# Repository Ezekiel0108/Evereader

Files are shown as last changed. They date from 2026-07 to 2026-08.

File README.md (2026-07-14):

# Evereader
## What is it?
It is an esp32-s3 module based e-reader with dual screens that should be easy enough for anyone to build and customize.
### Why does this project exist?
There are two main reasons:
1. I really wanted to make a project bigger than what i had done until now, i want to give back at least in some way to the foss community;
2. I have been getting a lot into reading lately and i really wanted an e-reader, but none of them actually felt right for me, either they where too big to put in a pocket or the smaller ones just didn't fit enough content for my taste.
### Why two screens?
1. Why not?
2. I really wanted to keep the form factor pocketable without sacrificing text on screen, so i put two!
#### State of developement
I am currently just ending the breadboard circuit, after that i want to start making the PCB and develop the firmware.
#### TO-DO list
- [x] Finish up the breadboard circuit.
- [ ] Finish up the PCB kicad project.
- [ ] Finish up the software.
- [ ] Refine what i can.
- [ ] Add images to the readme.

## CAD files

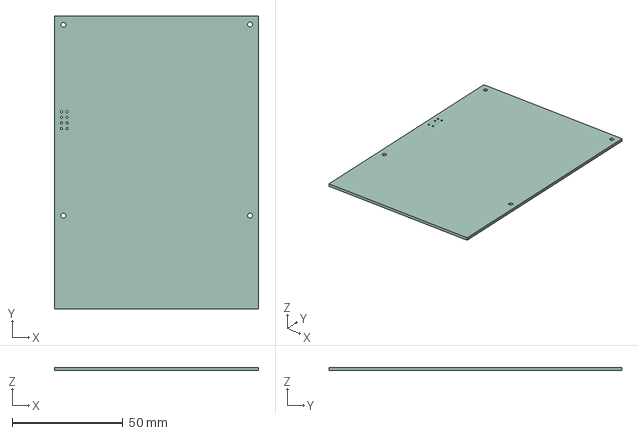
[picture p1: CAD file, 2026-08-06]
kicad/evereader/evereader.step
92.0 x 132.0 x 1.51 mm

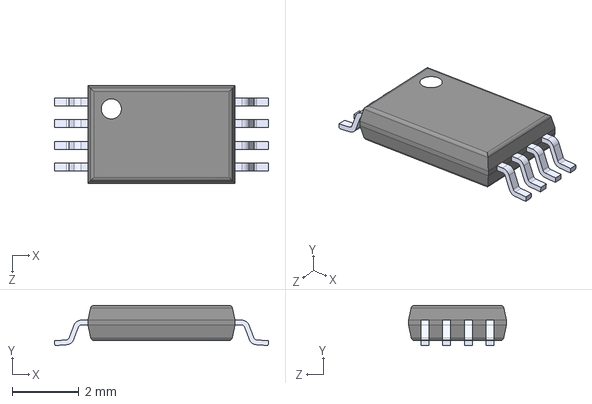
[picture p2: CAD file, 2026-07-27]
kicad/FS8205A/FS8205A.step
6.40 x 1.20 x 2.93 mm

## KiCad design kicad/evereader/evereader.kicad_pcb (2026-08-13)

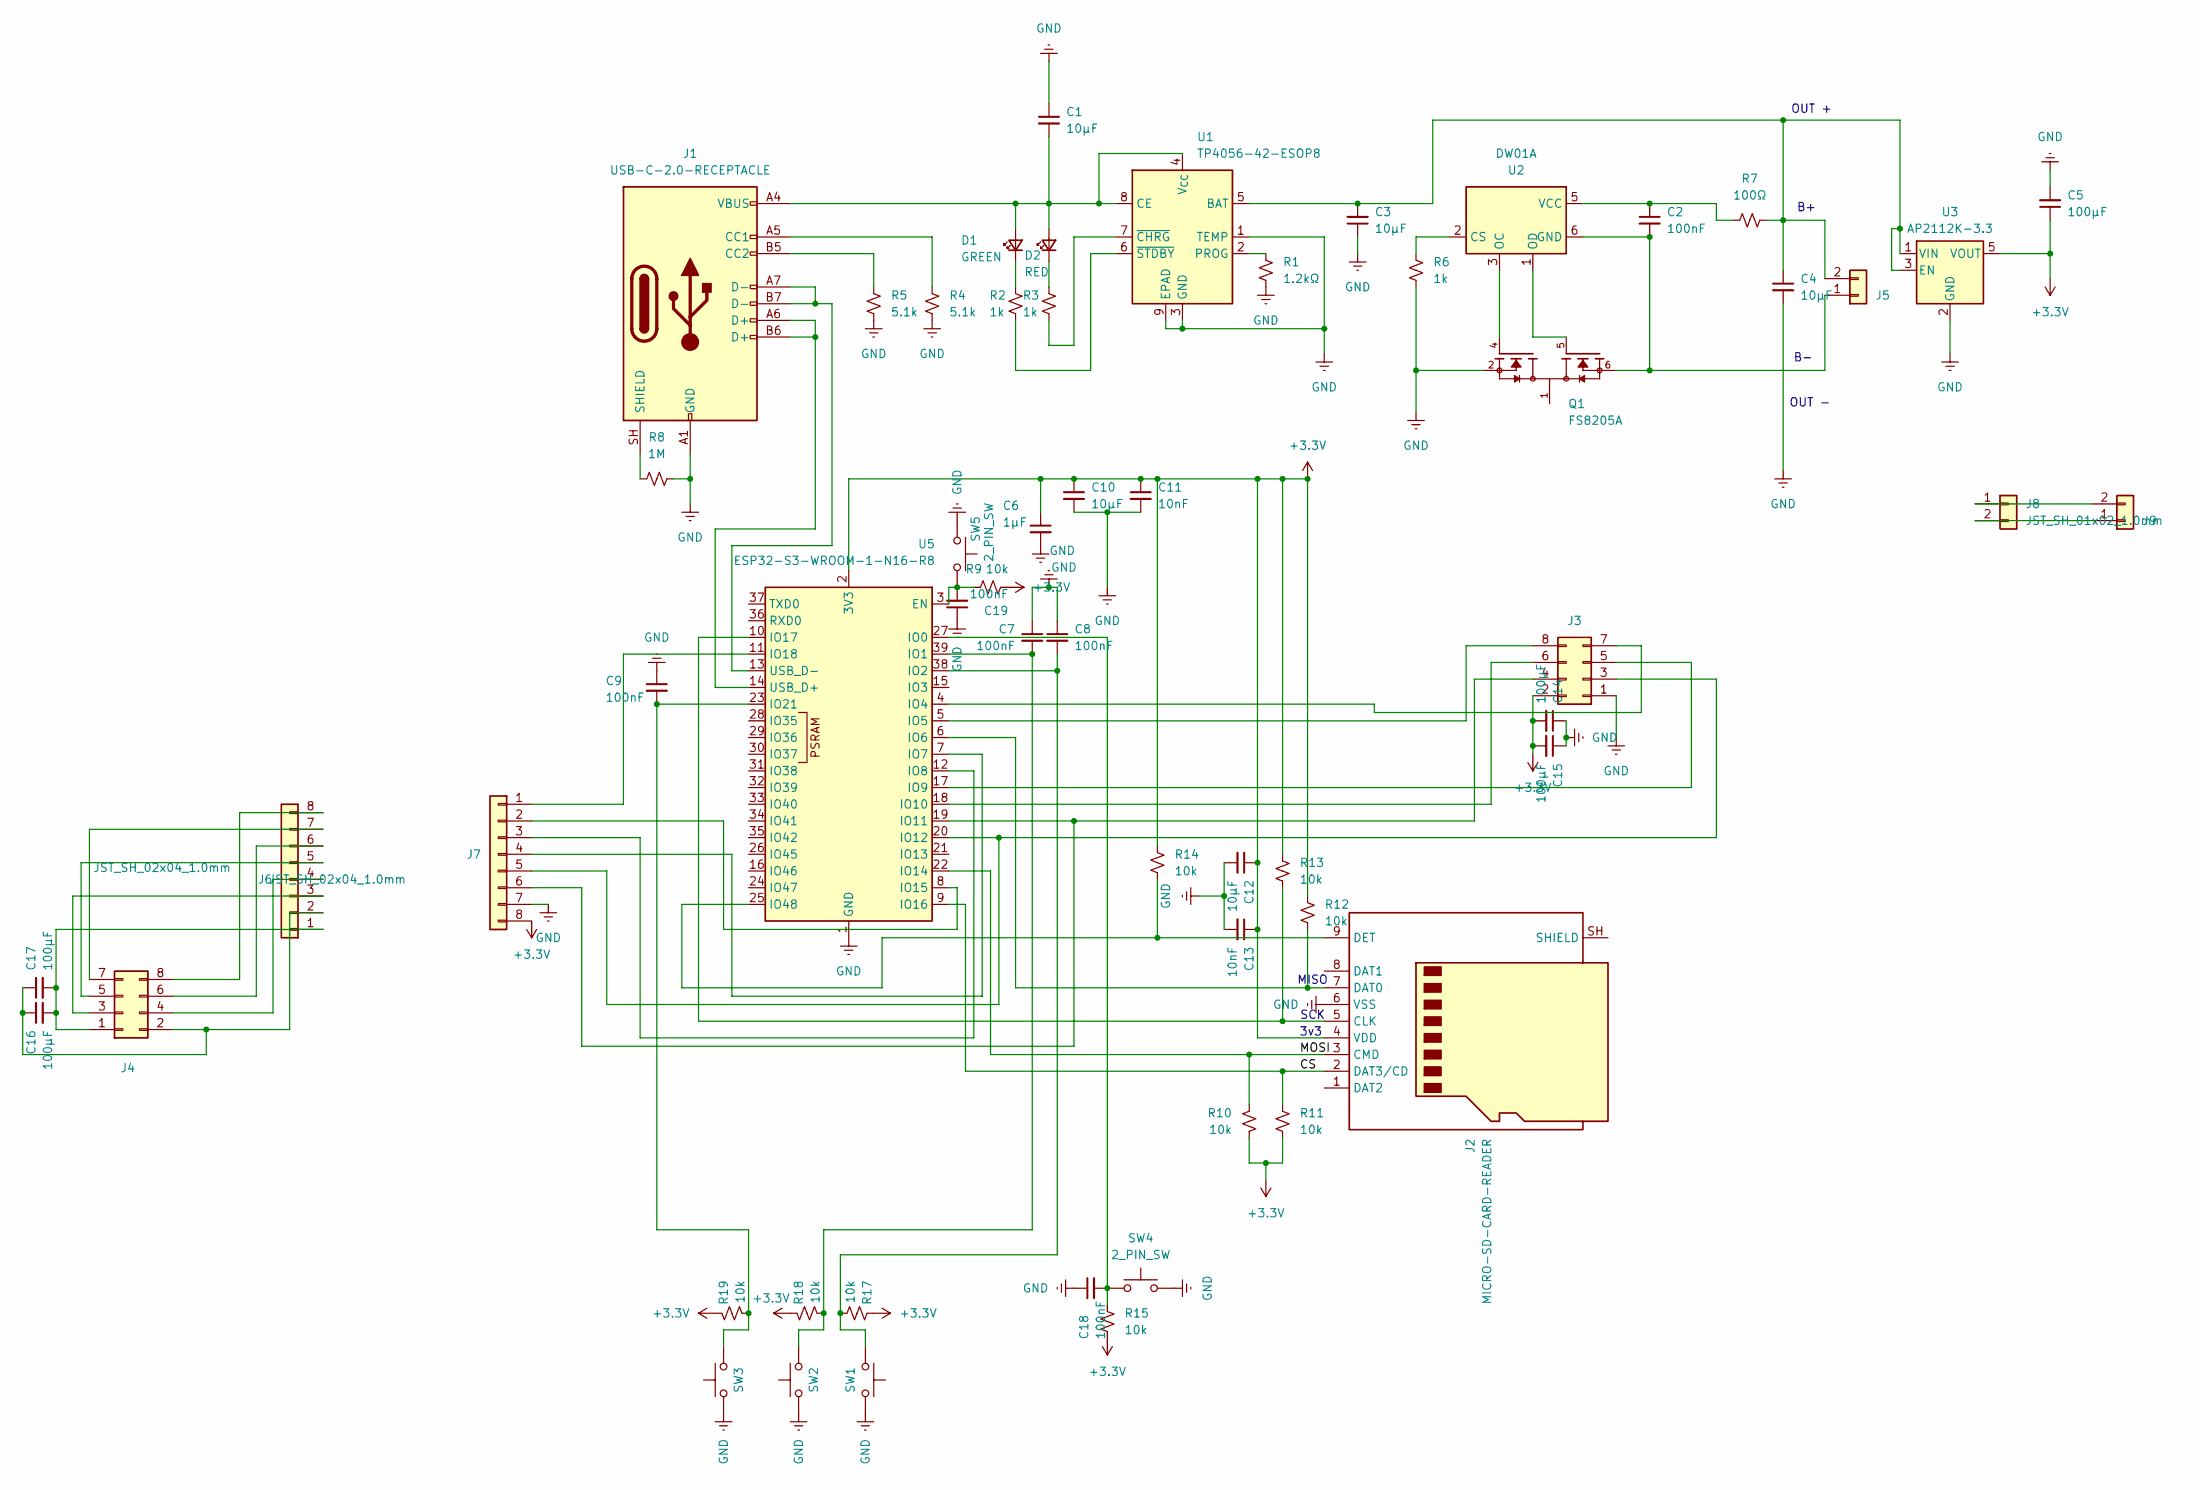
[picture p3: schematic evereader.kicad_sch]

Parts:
C1, C3, C4, C10, C12: 10μF; C_0805_2012Metric; JLCPCB C15850
C2, C7, C8, C9, C18, C19: 100nF; C_0805_2012Metric
C5: 100μF; C_1206_3216Metric; JLCPCB C28323
C6: 1μF; C_0805_2012Metric; JLCPCB C28323
C11, C13: 10nF; C_0805_2012Metric
C14, C15, C16, C17: 100μF; C_1206_3216Metric
D1: GREEN; LED_0805_2012Metric
D2: RED; LED_0805_2012Metric
J1: USB-C-2.0-RECEPTACLE; USB_C_Receptacle_HRO_TYPE-C-31-M-12; JLCPCB C165948
J2: MICRO-SD-CARD-READER; TF-SMD_TF-115-BCP9; JLCPCB C720505
J3, J4: PinHeader_2x04_P2.54mm_Vertical
J5, J8: JST_SH_01x02_1.0mm; CONN-SMD_2P-P1.00_SM02B-SRSS-TB-LF-SN; JLCPCB C160402
J6, J7: JST_SH_02x04_1.0mm; CONN-TH_SM08B-SRSS-TB-LF-SN; JLCPCB C160407
J9: PinHeader_1x02_P2.54mm_Vertical
Q1: FS8205A; TSSOP-8_L4.4-W3.0-P0.65-LS6.4-BL; PARTREV 1.7; JLCPCB C7525054
R1: 1.2kΩ; R_0805_2012Metric
R2, R3, R6: 1k; R_0805_2012Metric
R4, R5: 5.1k; R_0805_2012Metric
R7: 100Ω; R_0805_2012Metric
R8: 1M; R_0805_2012Metric
R9, R10, R11, R12, R13, R14, R15, R17, R18, R19: 10k; R_0805_2012Metric
SW1, SW2, SW3: SW_Push; SW_SPST_PTS645Sx43SMTR92
SW4, SW5: 2_PIN_SW; SW_Push_SPST_NO_Alps_SKRK
U1: TP4056-42-ESOP8; SOIC-8-1EP_3.9x4.9mm_P1.27mm_EP2.41x3.3mm_ThermalVias; JLCPCB C139797
U2: DW01A; SOT-23-6
U3: AP2112K-3.3; SOT-23-5
U5: ESP32-S3-WROOM-1-N16-R8; ESP32-S3-WROOM-1

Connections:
+3.3V: C5.1, C6.1, C10.1, C11.1, C12.1, C13.1, C14.2, C15.2, J2.4 (VDD), J3.2, J7.8, R9.2, R10.2, R11.2, R12.1, R13.1, R14.1, R15.2, R17.1, R18.1, R19.1, U3.5 (VOUT), U5.2 (3V3)
/CS: J2.2 (DAT3/CD), R11.1, U5.9 (IO16)
/MOSI: J2.3 (CMD), R10.1, U5.22 (IO14)
GND: C1.1, C3.1, C4.2, C5.2, C6.2, C7.1, C8.1, C9.1, C10.2, C11.2, C12.2, C13.2, C14.1, C15.1, C18.1, C19.1, J1.A1 (GND), J1.A12 (GND), J1.B1 (GND), J1.B12 (GND), J2.6 (VSS), J3.1, J7.7, Q1.2, Q1.3, R1.2, R4.2, R5.2, R6.2, R8.2, SW1.2, SW2.2, SW3.2, SW4.2, SW5.1, U1.1 (TEMP), U1.3 (GND), U1.9 (EPAD), U3.2 (GND), U5.1 (GND), U5.40 (GND), U5.41 (GND)
unnamed: C1.2, D1.2 (A), D2.2 (A), J1.A4 (VBUS), J1.A9 (VBUS), J1.B4 (VBUS), J1.B9 (VBUS), U1.4 (V_{CC}), U1.8 (CE)
unnamed: D1.1 (K), R2.1
unnamed: D2.1 (K), R3.1
unnamed: J1.A5 (CC1), R4.1
unnamed: J1.B5 (CC2), R5.1
unnamed: J1.SH (SHIELD), R8.1
unnamed: J2.5 (CLK), R13.2, U5.10 (IO17)
unnamed: J2.7 (DAT0), R12.2, U5.6 (IO6)
unnamed: J2.9 (DET), R14.2, U5.25 (IO48)
unnamed: J3.3, J7.5, U5.20 (IO12)
unnamed: J3.4, J7.6, U5.19 (IO11)
unnamed: J3.5, U5.17 (IO9)
unnamed: J3.6, U5.18 (IO10)
unnamed: J3.7, U5.4 (IO4)
unnamed: J3.8, U5.5 (IO5)
unnamed: C16.2, C17.2, J4.1, J6.1
unnamed: C16.1, C17.1, J4.2, J6.2
unnamed: J4.3, J6.3
unnamed: J4.4, J6.4
unnamed: J4.5, J6.5
unnamed: J4.6, J6.6
unnamed: J4.7, J6.7
unnamed: J4.8, J6.8
unnamed: C2.2, J5.1, Q1.6, Q1.7, U2.6 (GND)
unnamed: C3.2, C4.1, J5.2, R7.2, U1.5 (BAT), U3.1 (VIN), U3.3 (EN)
unnamed: J7.1, U5.11 (IO18)
unnamed: J7.2, U5.8 (IO15)
unnamed: J7.3, U5.12 (IO8)
unnamed: J7.4, U5.7 (IO7)
unnamed: J8.1, J9.2
unnamed: J8.2, J9.1
unnamed: Q1.1, Q1.8
unnamed: R1.1, U1.2 (PROG)
unnamed: R3.2, U1.7 (~CHRG)
unnamed: R2.2, U1.6 (~STDBY)
unnamed: R6.1, U2.2 (CS)
unnamed: Q1.4, U2.3 (OC)
unnamed: Q1.5, U2.1 (OD)
unnamed: C2.1, R7.1, U2.5 (VCC)
unnamed: C19.2, R9.1, SW5.2, U5.3 (EN)
unnamed: C18.2, R15.1, SW4.1, U5.27 (IO0)
unnamed: C7.2, R18.2, SW2.1, U5.39 (IO1)
unnamed: C8.2, R17.2, SW1.1, U5.38 (IO2)
unnamed: C9.2, R19.2, SW3.1, U5.23 (IO21)
unnamed: J1.A6 (D+), J1.B6 (D+), U5.14 (USB_D+)
unnamed: J1.A7 (D-), J1.B7 (D-), U5.13 (USB_D-)

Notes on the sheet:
MISO
SCK
3v3
OUT +
OUT -

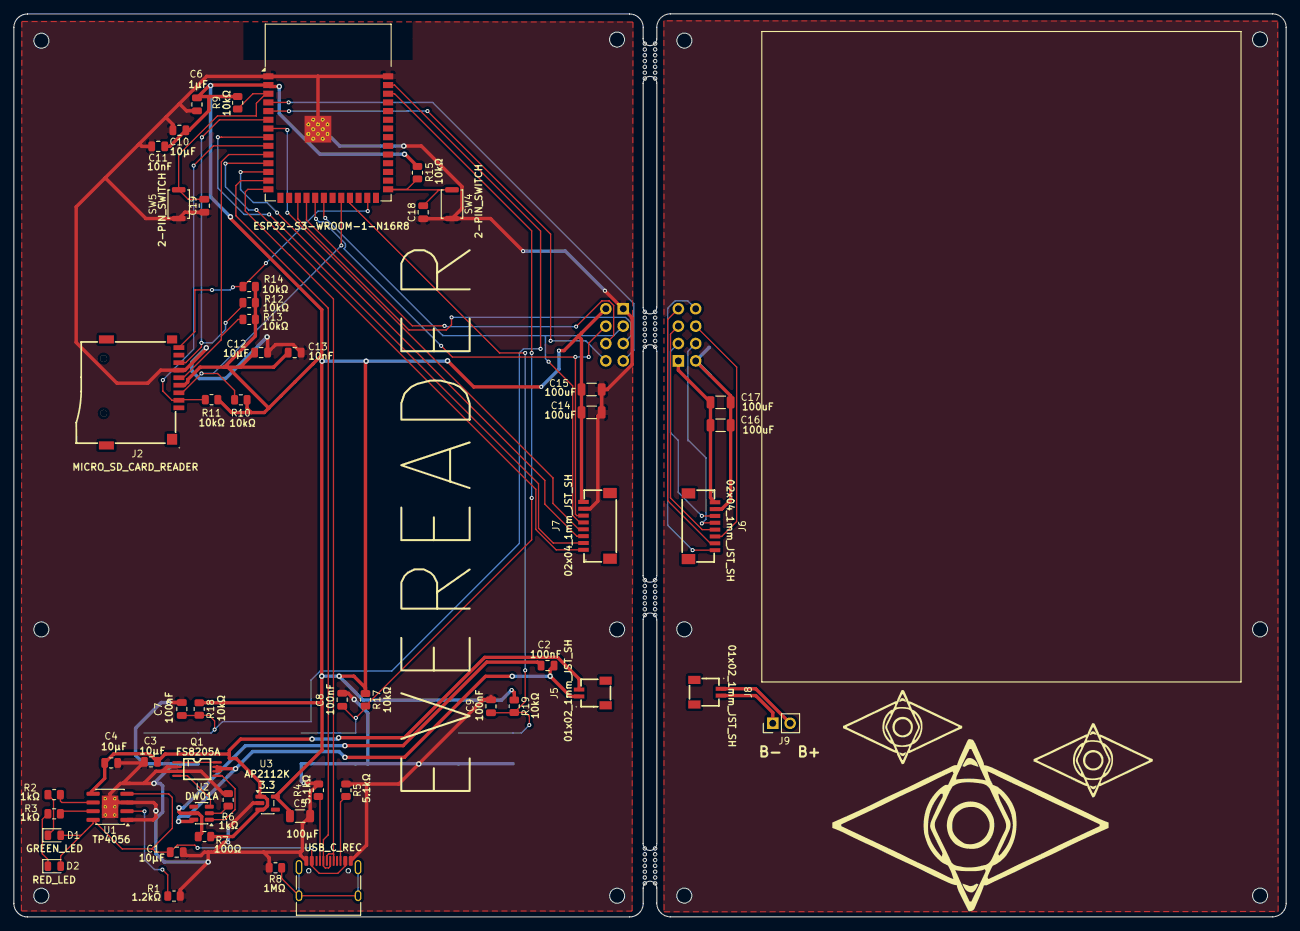
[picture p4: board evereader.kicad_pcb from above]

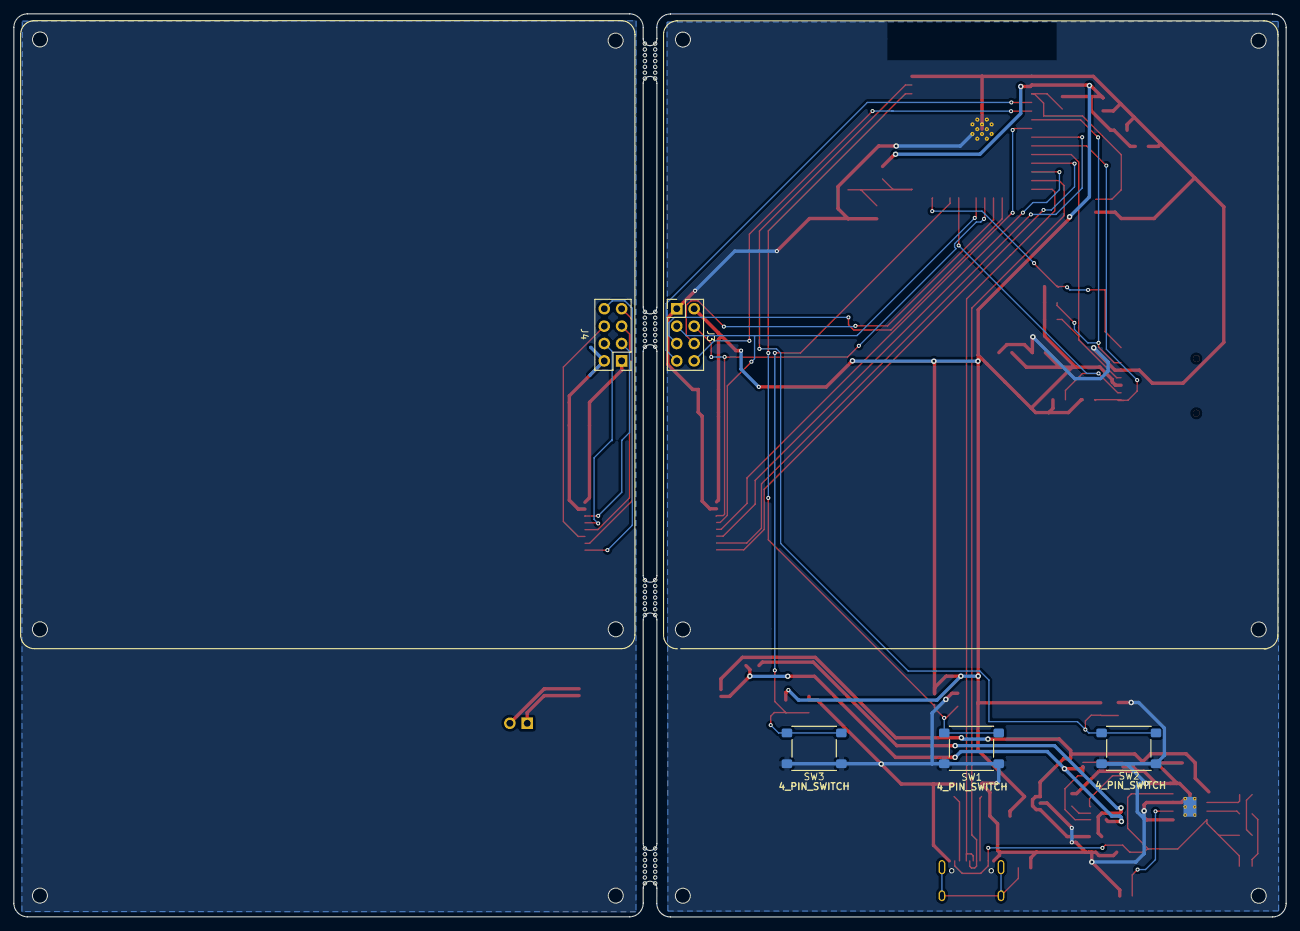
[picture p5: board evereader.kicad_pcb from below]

Board: 2 copper layers, 186.0 x 132.0 mm, 58 parts (5 on the bottom side), 50 nets.

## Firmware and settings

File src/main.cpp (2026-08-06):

#include <Arduino.h>
#include <GxEPD2_BW.h>
#include <FS.h>
#include <SD.h>
#include <SPI.h>
#include <OxProto_Regular14pt7b.h>

//Button pins
#define BUTTON_PIN_1 1
#define BUTTON_PIN_2 2
#define BUTTON_PIN_3 21

// Shared SPI pins
#define SPI_SCK  12
#define SPI_MOSI 11

// SD pins
#define SD_SCK_PIN  14
#define SD_MISO_PIN 17
#define SD_MOSI_PIN  6
#define SD_CS_PIN    16

//Right screen pin definitions
#define DC_R_PIN   9
#define RES_R_PIN  5
#define BUSY_R_PIN 4
#define SCREEN_R_CS_PIN 10

//Left screen pin definitions
#define DC_L_PIN   8
#define RES_L_PIN  15
#define BUSY_L_PIN 18
#define SCREEN_L_CS_PIN 7

GFXfont font = OxProto_Regular14pt7b;

int b1_state;
int b2_state;
int b3_state;
int b1_state_prev = HIGH;
int b2_state_prev = HIGH;
int b3_state_prev = HIGH;

SPIClass sharedSpi = SPIClass(FSPI);
SPIClass sdSpi = SPIClass(HSPI);

// Left display init
GxEPD2_BW<GxEPD2_420_GDEY042T81, GxEPD2_420_GDEY042T81::HEIGHT> displayLeft(
    GxEPD2_420_GDEY042T81(SCREEN_L_CS_PIN, DC_L_PIN, RES_L_PIN, BUSY_L_PIN)
);

//Right display init
GxEPD2_BW<GxEPD2_420_GDEY042T81, GxEPD2_420_GDEY042T81::HEIGHT> displayRight(
    GxEPD2_420_GDEY042T81(SCREEN_R_CS_PIN, DC_R_PIN, RES_R_PIN, BUSY_R_PIN)
);

void home_screen_print(){
  Serial.println("White paging everything!");

  do {
    displayRight.fillScreen(GxEPD_WHITE);
  } while (displayRight.nextPage());
  displayRight.hibernate();

  do {
    displayLeft.fillScreen(GxEPD_WHITE);
  } while (displayLeft.nextPage());
  displayLeft.hibernate();

}

void right_screen_print(){
  Serial.println("Printing to right screen!");
  do {
    displayRight.fillScreen(GxEPD_WHITE);
    displayRight.setCursor(20, 50);
    displayRight.printf("Right Screen!");

  } while (displayRight.nextPage());

  displayRight.hibernate();

}

void left_screen_print(){
  Serial.println("Printing to left screen!");
  do {
    displayLeft.fillScreen(GxEPD_WHITE);
    displayLeft.setCursor(20, 50);
    displayLeft.printf("Left Screen!");

  } while (displayLeft.nextPage());

  displayLeft.hibernate();

}

void setup() {
  Serial.begin(115200);
  for(int i = 3; i > 0; i--) { delay(1000); }
  
  //pinMode setup
  pinMode(SD_MISO_PIN, INPUT_PULLUP);
  pinMode(BUSY_L_PIN, INPUT_PULLUP);
  pinMode(BUSY_R_PIN, INPUT_PULLUP);
  pinMode(BUTTON_PIN_1, INPUT_PULLUP);
  pinMode(BUTTON_PIN_2, INPUT_PULLUP);
  pinMode(BUTTON_PIN_3, INPUT_PULLUP);

  //Screens setup
  Serial.println("Setting up right screen!");
  displayRight.setRotation(1);
  displayRight.setFont(&font);
  displayRight.setTextColor(GxEPD_BLACK);
  displayRight.setFullWindow();
  displayRight.firstPage();

  Serial.println("Printing left screen!");
  displayLeft.setRotation(1);
  displayLeft.setFont(&font);
  displayLeft.setTextColor(GxEPD_BLACK);
  displayLeft.setFullWindow();
  displayLeft.firstPage();

  //Booting up SPIs and selecting display ones
  sharedSpi.begin(SPI_SCK, -1, SPI_MOSI, -1);
  sdSpi.begin(SD_SCK_PIN, SD_MISO_PIN, SD_MOSI_PIN, -1);
  displayLeft.epd2.selectSPI(sharedSpi, SPISettings(2000000, MSBFIRST, SPI_MODE0));
  displayRight.epd2.selectSPI(sharedSpi, SPISettings(2000000, MSBFIRST, SPI_MODE0));
  
  //Initializing both displays
  displayLeft.init(115200, true, 50, false);
  displayRight.init(115200, true, 50, false);

  //Card mount and display to serial
  Serial.println("Pinging card...");
  if(!SD.begin(SD_CS_PIN, sdSpi, 1000000)) {
    Serial.println("[ERROR]: Mount Failed. Board is physically unresponsive.");
    return;
  }
  Serial.println("[SUCCESS]: Card Mounted!");
  uint64_t cardSize = SD.cardSize() / (1024 * 1024);
  Serial.printf("Size: %llu MB\n", cardSize);
}

void loop() {
  b1_state = digitalRead(BUTTON_PIN_1);
  b2_state = digitalRead(BUTTON_PIN_2);
  b3_state = digitalRead(BUTTON_PIN_3);

  if(b1_state_prev == HIGH && b1_state == LOW){
    left_screen_print();
  }
  if(b2_state_prev == HIGH && b2_state == LOW){
    home_screen_print();
  }
  if(b3_state_prev == HIGH && b3_state == LOW){
    right_screen_print();
  }

  b1_state_prev = b1_state;
  b2_state_prev = b2_state;
  b3_state_prev = b3_state;
}

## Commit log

2026-06-10 Added logic for second screen and replaced old font with 0xProto_Regular
    [main.cpp]
2026-06-10 Fixed up right screen lock and tidied up code a bit
    [main.cpp]
2026-06-14 Fixed up some code stuff
    [main.cpp]
2026-06-28 Gave SD a separate SPI bus!
2026-07-14 Worked on basic code for testing out functionality of finished circuit
2026-07-27 added .gitignore
    [evereader.kicad_pcb, evereader.kicad_sch]
2026-07-27 removed kicad folder from project, going to only put output files here from now on
    [FS8205A.step, evereader.kicad_pcb, evereader.kicad_sch]
2026-07-29 removed FS8205A lib from repo
    [FS8205A.step]
2026-07-30 fixed up buttons GPIO pins
    [main.cpp]
2026-08-06 added the whole kicad folder back in
    [FS8205A.step, evereader.kicad_pcb, evereader.kicad_sch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]
2026-08-06 added some stuff that initial commit didn't add for kicad
2026-08-06 Did a few simple fixes for the firmware, made fonts a variable
    [main.cpp]
2026-08-08 finished the PCB, finally
    [bom.csv, designators.csv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]
2026-08-09 fixed up some stuff on the PCB
    [evereader.kicad_pcb]
2026-08-09 fixed jst connector having inverted wiring on the pcb and added nomenclatures for each component
    [evereader.kicad_pcb, evereader.kicad_sch]
2026-08-09 added keepout zone i had previously removed from esp32
    [evereader.kicad_pcb]
2026-08-09 added production folder to gitignore
    [bom.csv, designators.csv, positions.csv]
2026-08-10 fixed up PCB schematics component values
    [evereader.kicad_pcb, evereader.kicad_sch]
2026-08-12 made ldo 1uF capacitor a 100uF
    [evereader.kicad_pcb, evereader.kicad_sch]
2026-08-13 actually swapped the footprint of C5 from 0805 to 1026
    [evereader.kicad_pcb, evereader.kicad_sch]
